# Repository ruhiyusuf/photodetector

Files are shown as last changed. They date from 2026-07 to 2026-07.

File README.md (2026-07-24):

# Balanced Homodyne Photodetector

This repository contains the design, simulation, fabrication, and measurement files for a balanced homodyne photodetector developed for quantum optics experiments.

## Final Designs

The completed detector designs are stored in `final_designs/`:

- `Photodetector_v2_3_HI.asc` — final high-gain design
- `Photodetector_v2_3_LO.asc` — final low-gain design

Both schematics share the custom LTspice symbols and models stored in the same directory.

## Measured Performance

- High-gain configuration: approximately 36 dB gain
- High-gain shot-noise separation: approximately 25 dB
- Low-gain configuration: approximately 30 dB gain
- Low-gain shot-noise separation: approximately 12 dB
- Measured bandwidth: approximately 70 kHz to 10 MHz

## Repository Structure

```text
final_designs/         Completed high- and low-gain LTspice designs
experimental/          Incomplete design explorations
archive/               Earlier design revisions and legacy experiments
pcb/                   Fabrication outputs, CAD files, BOMs, and Gerbers
measurements/          Analysis scripts, measurement data, and plots
docs/                  Documentation images and figures

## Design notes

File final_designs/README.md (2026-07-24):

# Final Designs

This directory contains the completed high-gain and low-gain balanced photodetector LTspice designs.

Both schematics share the custom symbols and simulation models stored in this directory.

- `Photodetector_v2_3_HI.asc` — final high-gain design
- `Photodetector_v2_3_LO.asc` — final low-gain design

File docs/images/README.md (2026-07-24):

# Documentation Images

Repository figures, schematics, PCB renders, measurement plots, and hardware photographs belong here.

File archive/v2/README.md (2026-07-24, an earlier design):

# Archived Revision

This directory contains an earlier self-contained LTspice design revision.

The custom symbols and simulation models are included so the schematic can be opened independently. Generated LTspice outputs are excluded from version control.

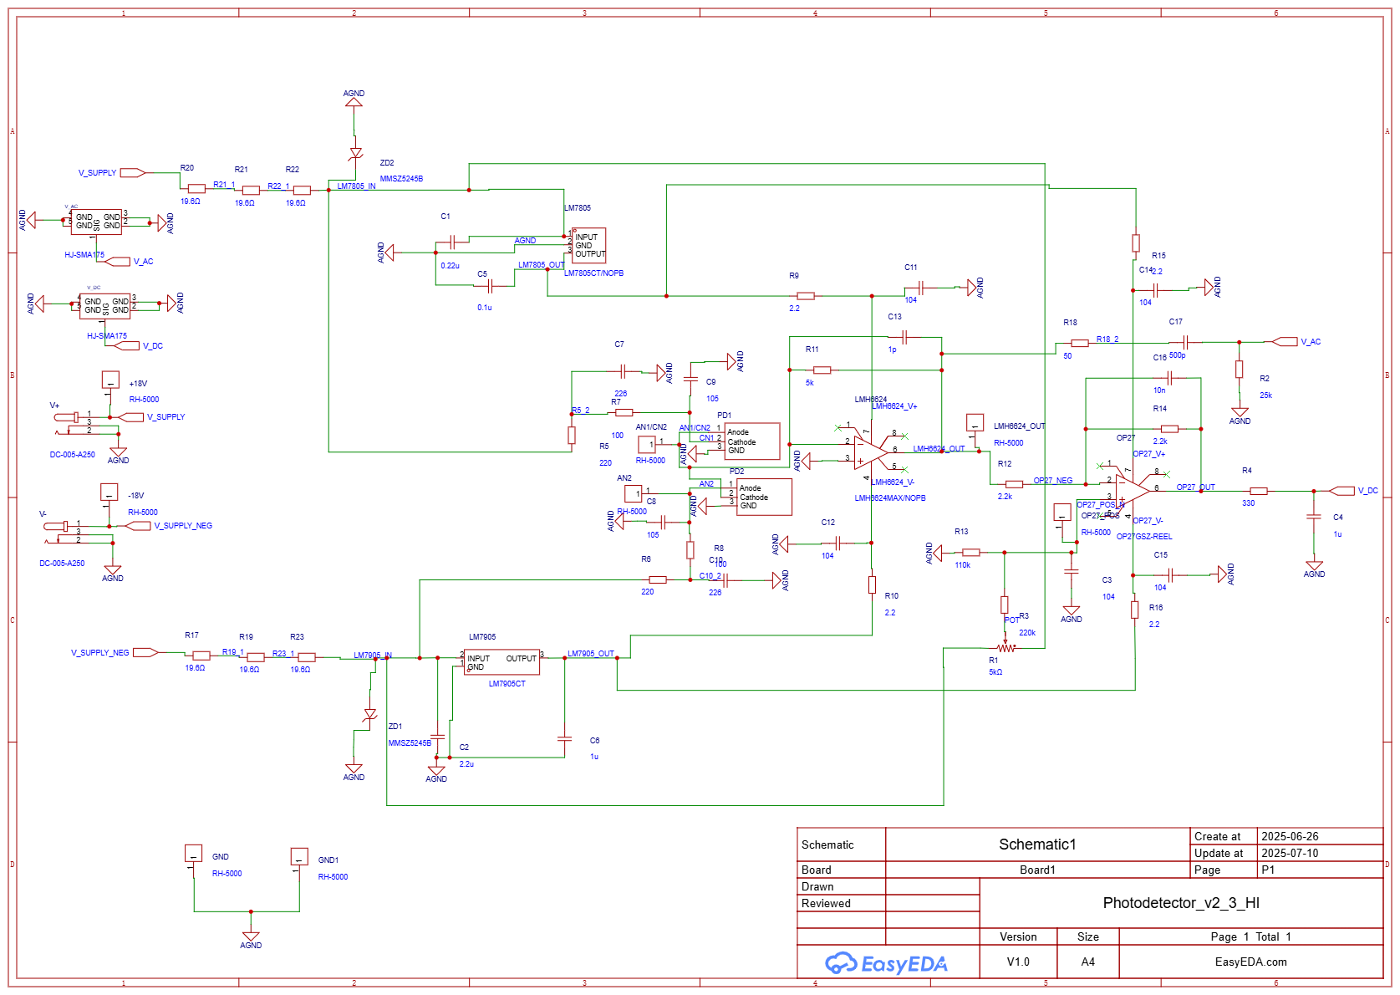
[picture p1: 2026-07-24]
pcb/high_gain/design_exports/SCH_Schematic1_1-P1_2025-07-10.png

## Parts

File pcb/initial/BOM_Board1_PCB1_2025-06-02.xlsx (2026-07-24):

No. | Quantity | Comment | Designator | Footprint | Value | Manufacturer Part | Manufacturer | Supplier Part | Supplier
1 | 11 | RH-5000 | AN1/CN2,AN2,GND,GND1,GND2,GND3,GND4,GND5,LMH6624_OUT,V+1,V-1 | TEST-TH_BD2.54-P1.4_RED |  | RH-5000 | 荣和 | C5277086 | LCSC
2 | 1 | 0.22u | C1 | C0603 | 0.22u
3 | 1 | 2.2u | C2 | C0603 | 2.2u
4 | 5 | 104 | C3,C11,C12,C14,C15 | C0603 | 104
5 | 2 | 1u | C4,C6 | C0603 | 1u
6 | 1 | 0.1u | C5 | C0603 | 0.1u
7 | 2 | 226 | C7,C10 | C0603 | 226
8 | 2 | 105 | C8,C9 | C0603 | 105
9 | 1 | 1.5p | C13 | C0603 | 1.5p
10 | 2 | 10n | C16,C17 | C0603 | 10n
11 | 2 | BZX84C15-7-F | D3,D4 | SOT-23-3_L2.9-W1.3-P1.90-LS2.4-BR |  | BZX84C15-7-F | DIODES(美台) | C500789 | LCSC
12 | 1 | LM7805CT/NOPB | LM7805 | TO-220-3_L10.0-W4.5-P2.54-T |  | LM7805CT/NOPB | TI(德州仪器) | C50931 | LCSC
13 | 1 | LM7905CT | LM7905 | TO-220-3_L9.9-W4.5-P2.54-L |  | LM7905CT | HGSEMI(华冠) | C7432217 | LCSC
14 | 1 | LMH6624MAX/NOPB | LMH6624 | SOIC-8_L4.9-W3.9-P1.27-LS6.0-BL |  | LMH6624MAX/NOPB | TI(德州仪器) | C486023 | LCSC
15 | 1 | OP27GSZ-REEL | OP27 | SOIC-8_L4.9-W3.9-P1.27-LS6.0-BL |  | OP27GSZ-REEL | ADI(亚德诺) | C581242 | LCSC
16 | 2 | PD | PD1,PD2 | HQE Detector
17 | 1 | 5k | R1 | R0603 | 5k
18 | 1 | 100k | R2 | R0603 | 100k
19 | 1 | 220k | R3 | R0603 | 220k
20 | 1 | 330 | R4 | R0603 | 330
21 | 2 | 220 | R5,R6 | R0603 | 220
22 | 2 | 100 | R7,R8 | R0603 | 100
23 | 4 | 2.2 | R9,R10,R15,R16 | R0603 | 2.2
24 | 2 | 1k | R11,R13 | R0603 | 1k
25 | 2 | 2.2k | R12,R14 | R0603 | 2.2k
26 | 1 | 50 | R17 | R0603 | 50
27 | 2 | DC-005-A250 | V+,V- | DC-IN-TH_DC-005-A250 |  | DC-005-A250 | XUNPU(讯普) | C720558 | LCSC
28 | 2 | HJ-SMA175 | V_AC,V_DC | SMA-TH_HJ-SMA175 |  | HJ-SMA175 | 皇捷 | C1509213 | LCSC

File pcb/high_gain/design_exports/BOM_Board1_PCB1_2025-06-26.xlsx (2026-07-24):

No. | Quantity | Comment | Designator | Footprint | Value | Manufacturer Part | Manufacturer | Supplier Part | Supplier
1 | 8 | RH-5000 | +18V,-18V,AN1/CN2,AN2,GND,GND1,LMH6624_OUT,OP27_POS | TEST-TH_BD2.54-P1.4_RED |  | RH-5000 | 荣和 | C5277086 | LCSC
2 | 1 | 0.22u | C1 | C0603 | 0.22u
3 | 1 | 2.2u | C2 | C0603 | 2.2u
4 | 5 | 104 | C3,C11,C12,C14,C15 | C0603 | 104
5 | 2 | 1u | C4,C6 | C0603 | 1u
6 | 1 | 0.1u | C5 | C0603 | 0.1u
7 | 2 | 226 | C7,C10 | C0603 | 226
8 | 2 | 105 | C8,C9 | C0603 | 105
9 | 1 | 1p | C13 | C0603 | 1p
10 | 1 | 10n | C16 | C0603 | 10n
11 | 1 | 500p | C17 | C0603 | 500p
12 | 1 | LM7805CT/NOPB | LM7805 | TO-220-3_L10.0-W4.5-P2.54-T |  | LM7805CT/NOPB | TI(德州仪器) | C50931 | LCSC
13 | 1 | LM7905CT | LM7905 | TO-220-3_L9.9-W4.5-P2.54-L |  | LM7905CT | HGSEMI(华冠) | C7432217 | LCSC
14 | 1 | LMH6624MAX/NOPB | LMH6624 | SOIC-8_L4.9-W3.9-P1.27-LS6.0-BL |  | LMH6624MAX/NOPB | TI(德州仪器) | C486023 | LCSC
15 | 1 | OP27GSZ-REEL | OP27 | SOIC-8_L4.9-W3.9-P1.27-LS6.0-BL |  | OP27GSZ-REEL | ADI(亚德诺) | C581242 | LCSC
16 | 2 | PD | PD1,PD2 | HQE Detector
17 | 1 | 5kΩ | R1 | RES-ADJ-TH_3362P | 5kΩ | 3362P-1-502 | BOCHEN(博晨) | C118903 | LCSC
18 | 1 | 25k | R2 | R0603 | 25k
19 | 1 | 220k | R3 | R0603 | 220k
20 | 1 | 330 | R4 | R0603 | 330
21 | 2 | 220 | R5,R6 | R0603 | 220
22 | 2 | 100 | R7,R8 | R0603 | 100
23 | 4 | 2.2 | R9,R10,R15,R16 | R0603 | 2.2
24 | 1 | 5k | R11 | R0603 | 5k
25 | 2 | 2.2k | R12,R14 | R0603 | 2.2k
26 | 1 | 110k | R13 | R0603 | 110k
27 | 6 | 19.6Ω | R17,R19,R20,R21,R22,R23 | R1206 | 19.6Ω | FRC1206F19R6TS | FOJAN(富捷) | C2933621 | LCSC
28 | 1 | 50 | R18 | R0603 | 50
29 | 2 | DC-005-A250 | V+,V- | DC-IN-TH_DC-005-A250 |  | DC-005-A250 | XUNPU(讯普) | C720558 | LCSC
30 | 2 | HJ-SMA175 | V_AC,V_DC | SMA-TH_HJ-SMA175 |  | HJ-SMA175 | 皇捷 | C1509213 | LCSC
31 | 2 | MMSZ5245B | ZD1,ZD2 | SOD-123_L2.8-W1.8-LS3.7-RD |  | MMSZ5245B | CJ(江苏长电/长晶) | C2126 | LCSC

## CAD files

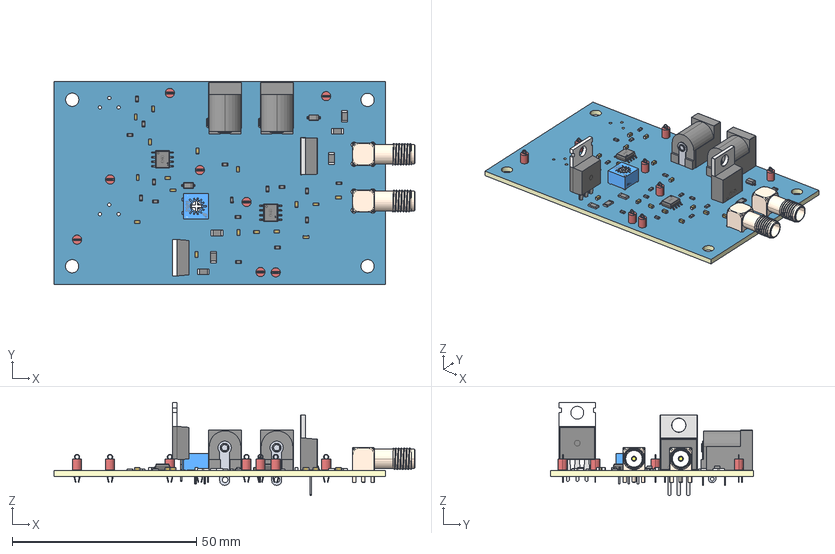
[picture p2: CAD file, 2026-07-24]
pcb/low_gain/design_exports/3D_PCB1_2025-08-29.step
97.9 x 55.0 x 25.3 mm
Board~WAR9
TopCopper~WAR9
BottomCopper~WAR9
TopFpcStiffener~WAR9
BottomFpcStiffener~WAR9
R0603~R0603~WAR9 x 16
R1206~R1206_L3.2-W1.6-H0.6~WAR9 x 6
C0603~C0603_L1.6-W0.8-H0.8~WAR9 x 17
DC-IN-TH_DC-005-A250~DC-IN-TH_DC-005-A250~WAR9 x 2
SOIC-8_L4.9-W3.9-P1.27-LS6.0-BL~SOIC-8_L4.9-W3.9-H1.7-LS6.0-P1.27~WAR9 x 2
TEST-TH_BD2.54-P1.4_RED~TEST-TH_BD2.54-P1.4_RED~WAR9 x 8
SOD-123_L2.8-W1.8-LS3.7-RD~SOD-123_L2.8-W1.8-LS3.7-RD~WAR9 x 2
TO-220-3_L10.0-W4.5-P2.54-T~TO-220-3_L10.0-W4.5-P2.54~WAR9
SMA-TH_HJ-SMA175~SMA-TH_HJ-SMA175~WAR9 x 2
RES-ADJ-TH_3362P~3362P~WAR9
TO-220-3_L9.9-W4.5-P2.54-L~TO-220-3_L9.9-W4.5-P2.54-L~WAR9

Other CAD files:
pcb/enclosure/Photodetector_Case.dwg
pcb/low_gain/design_exports/3D_PCB1_2025-08-29/3D_PCB1_2025-08-29/+18V~TEST-TH_BD2.54-P1.4_RED~TEST-TH_BD2.54-P1.4_RED~WAR9.iam
pcb/low_gain/design_exports/3D_PCB1_2025-08-29/3D_PCB1_2025-08-29/3D_PCB1_2025-08-29.iam
pcb/low_gain/design_exports/3D_PCB1_2025-08-29/3D_PCB1_2025-08-29/Board~WAR9.ipt
pcb/low_gain/design_exports/3D_PCB1_2025-08-29/3D_PCB1_2025-08-29/C0603~C0603_L1.6-W0.8-H0.8~WAR9.ipt
pcb/low_gain/design_exports/3D_PCB1_2025-08-29/3D_PCB1_2025-08-29/C1~C0603~C0603_L1.6-W0.8-H0.8~WAR9.iam
pcb/low_gain/design_exports/3D_PCB1_2025-08-29/3D_PCB1_2025-08-29/DC-IN-TH_DC-005-A250~DC-IN-TH_DC-005-A250~WAR9.ipt
pcb/low_gain/design_exports/3D_PCB1_2025-08-29/3D_PCB1_2025-08-29/LM7805~TO-220-3_L10.0-W4.5-P2.54-T~TO-220-3_L10.0-W4.5-P2.54~WAR9.iam
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

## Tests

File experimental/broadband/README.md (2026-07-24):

# Broadband Prototype

This directory contains an unfinished broadband photodetector design exploration.

The design was started as a possible extension of the Version 2.3 detectors, but it was not completed or validated as final hardware.

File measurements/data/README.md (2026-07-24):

# Measurement Data

Experimental measurement data should be stored here in reusable formats such as CSV.

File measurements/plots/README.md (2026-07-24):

# Measurement Plots

Generated and publication-ready measurement figures belong here.

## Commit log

2026-07-24 reorganize git
    [+18V~TEST-TH_BD2.54-P1.4_RED~TEST-TH_BD2.54-P1.4_RED~WAR9.iam, 3D_PCB1_2025-08-29.0002.iam, 3D_PCB1_2025-08-29.iam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]
2026-07-24 Reorganize photodetector design repository
    [+18V~TEST-TH_BD2.54-P1.4_RED~TEST-TH_BD2.54-P1.4_RED~WAR9.iam, 3D_PCB1_2025-08-29.0002.iam, 3D_PCB1_2025-08-29.iam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]
2026-07-28 connected voltage regulators to rest of schematic
